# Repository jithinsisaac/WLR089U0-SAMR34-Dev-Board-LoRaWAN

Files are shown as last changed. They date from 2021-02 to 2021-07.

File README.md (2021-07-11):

### WLR089U0-SAMR34-Dev-Board-LoRaWAN
Development board for Microchip's WLR089U0 LoRaWAN module consisting of the SAMR34 SiP IC 

### PCB Information:
1.  SAMR34 based SiP
2.  Inbuilt u.Fl connector, so no need to worry about RF tuning and impedance matching for PCB tracks
3.  Sleep current of ~2.4uA in Standby mode!
4.  Powered from the USB port
5.  Microchip MCP1700 3.3V LDO
6.  Inbuilt CH340E USB-UART converter. No need for any extra adapter. Serial comm works directly via the USB. CH340E does not require external crystals.
7.  SWD programming via the Cortex debug pin

### Firmware for the board
1.  Use Microchip Studio for firmware programming
2.  Install/Update Microchip ASF 3.48
3.  Open a New Example Project, search for SAMR34
4.  Use 'LoRaWAN Mote Application - SAMR34 Xplained Pro' project
5.  Be sure to choose MLS 1_0_P_4 from ASF version 3.48 (requires LoRaWAN core 1.0.2)
6.  Newer version of MLS 1_0_P_5 requires LoRaWAN core 1.0.4, which may not be compatible with many networks.

### Snapshots:
1. PCB Front
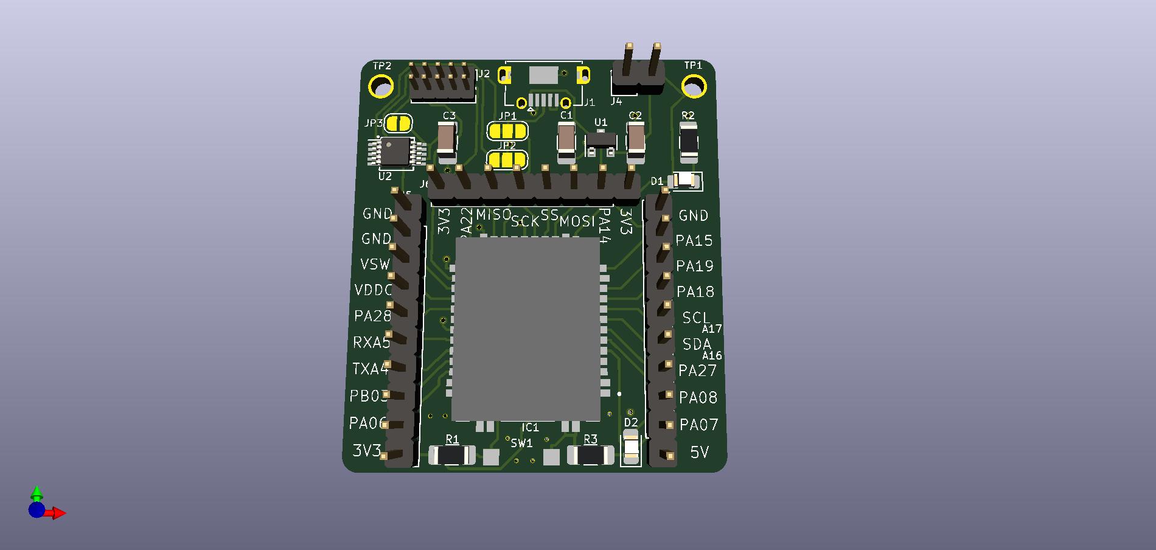
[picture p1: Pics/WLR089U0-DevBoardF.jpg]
Front PCB

2. PCB Back
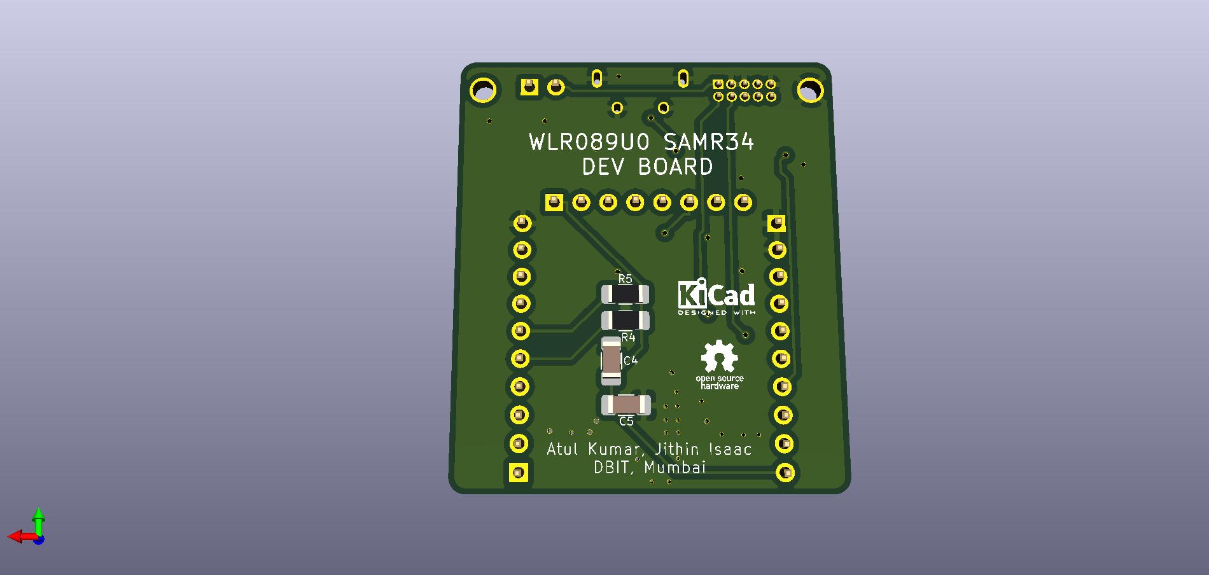
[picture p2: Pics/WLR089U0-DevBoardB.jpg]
Back PCB

3. Finished product 
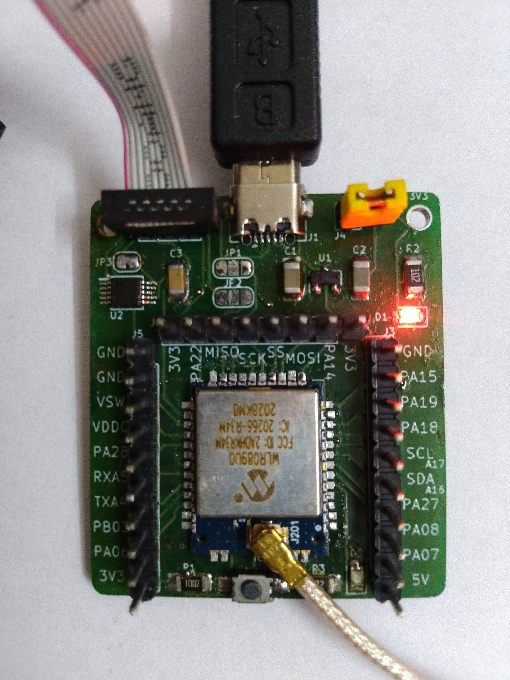
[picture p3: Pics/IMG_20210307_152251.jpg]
Product


### Credits
Atul Kumar  (Third Year student, AY2020-2021)  
Jithin Saji Isaac (Assistant Professor, Dept. of EXTC)  
Don Bosco Institute of Technology, Mumbai  
Feb 2021

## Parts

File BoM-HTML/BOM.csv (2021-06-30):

Designator | Quantity | Value | Manufacturer_Part_Number
C1 C2 | 2 | 1u | 1206B105K250CT
C3 C4 C5 | 3 | 100n | 1206B104K500CT
D1 | 1 | Red | RD-LED-0805
D2 | 1 | Green | RD-LED-0805
IC1 | 1 | WLR089U0-I_RM | WLR089U0-I/RM
J1 | 1 | USB_B_Micro | DNP
J2 | 1 | Conn_ARM_JTAG_SWD_10 | DNP
J3 J5 | 2 | Conn_01x10_Female | DNP
J4 | 1 | Conn_01x02_Male | DNP
J6 | 1 | Conn_01x08_Male | DNP
JP1 JP2 | 2 | SolderJumper_3_Bridged12 | DNP
JP3 | 1 | SolderJumper_2_Open | DNP
R1 | 1 | 10k | DNP
R2 R3 | 2 | 1k | DNP
R4 R5 | 2 | 4.7k | DNP
SW1 | 1 | SW_Push | DNP
TP1 TP2 | 2 | TestPoint | DNP
U1 | 1 | MCP1700-3302E_SOT23 | DNP
U2 | 1 | CH304E | DNP

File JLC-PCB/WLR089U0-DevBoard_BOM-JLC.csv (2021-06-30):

Comment | Designator | Footprint | LCSC
1u | C1,C2 | Capacitor_SMD:C_1206_3216Metric_Pad1.33x1.80mm_HandSolder | C412632
100n | C3,C4,C5 | Capacitor_SMD:C_1206_3216Metric_Pad1.33x1.80mm_HandSolder | C692631
Red | D1 | LED_SMD:LED_0805_2012Metric_Pad1.15x1.40mm_HandSolder | C84260
Green | D2 | LED_SMD:LED_0805_2012Metric_Pad1.15x1.40mm_HandSolder | C84260
WLR089U0-I_RM | IC1 | SamacSys_Parts:WLR089U0IRM
USB_B_Micro | J1 | Connector_USB:USB_Micro-AB_Molex_47590-0001 | C77238
Conn_ARM_JTAG_SWD_10 | J2 | Connector_PinHeader_1.27mm:PinHeader_2x05_P1.27mm_Vertical | C124387
Conn_01x10_Female | J3,J5 | Connector_PinHeader_2.54mm:PinHeader_1x10_P2.54mm_Vertical | C57369
Conn_01x02_Male | J4 | Connector_PinHeader_2.54mm:PinHeader_1x02_P2.54mm_Vertical | C124375
Conn_01x08_Male | J6 | Connector_PinHeader_2.54mm:PinHeader_1x08_P2.54mm_Vertical | C124381
SolderJumper_3_Bridged12 | JP1,JP2 | Jumper:SolderJumper-3_P1.3mm_Bridged12_RoundedPad1.0x1.5mm_NumberLabels
SolderJumper_2_Open | JP3 | Jumper:SolderJumper-2_P1.3mm_Open_RoundedPad1.0x1.5mm
10k | R1 | Resistor_SMD:R_1206_3216Metric_Pad1.42x1.75mm_HandSolder | C17902
1k | R2,R3 | Resistor_SMD:R_1206_3216Metric_Pad1.42x1.75mm_HandSolder | C1469
4.7k | R4,R5 | Resistor_SMD:R_1206_3216Metric_Pad1.42x1.75mm_HandSolder | C104821
SW_Push | SW1 | WLR089u0-DevBoard:Tactile Switch 3x4x2mm | C455280
TestPoint | TP1,TP2 | MountingHole:MountingHole_2.2mm_M2_DIN965_Pad_TopBottom
MCP1700-3302E_SOT23 | U1 | Package_TO_SOT_SMD:SOT-23 | C39051
CH304E | U2 | Package_SO:MSOP-10_3x3mm_P0.5mm | C99652

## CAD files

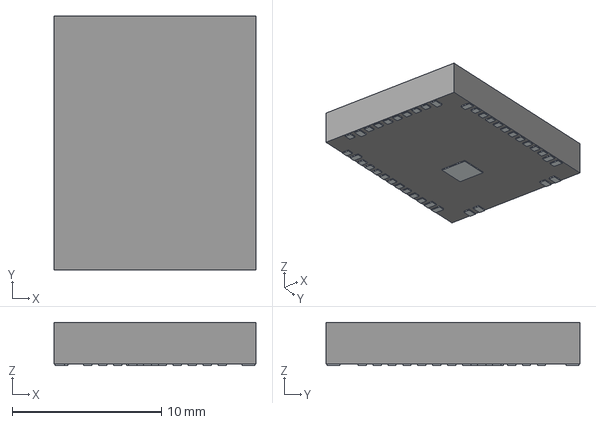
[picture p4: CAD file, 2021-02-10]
3DShapes/WLR089U0-I_RM.stp
13.5 x 17.0 x 2.90 mm
Pins

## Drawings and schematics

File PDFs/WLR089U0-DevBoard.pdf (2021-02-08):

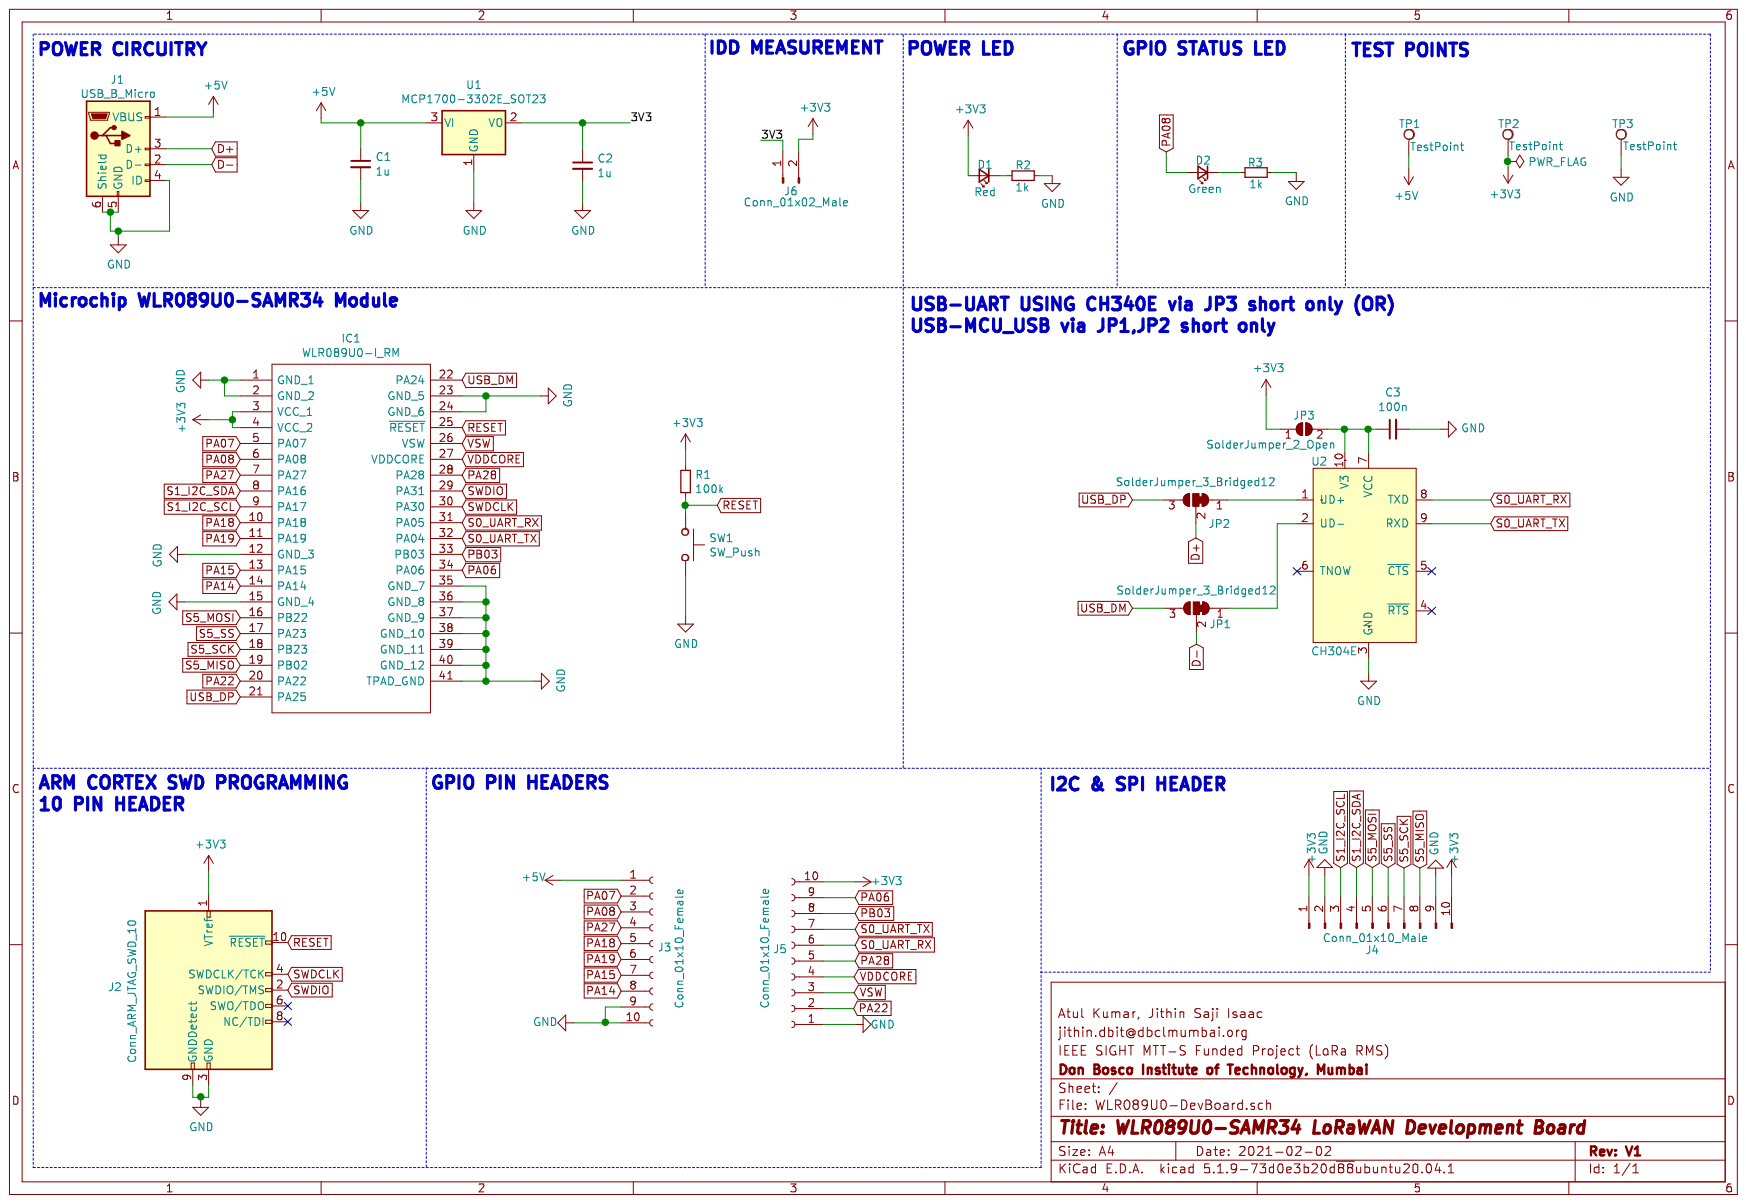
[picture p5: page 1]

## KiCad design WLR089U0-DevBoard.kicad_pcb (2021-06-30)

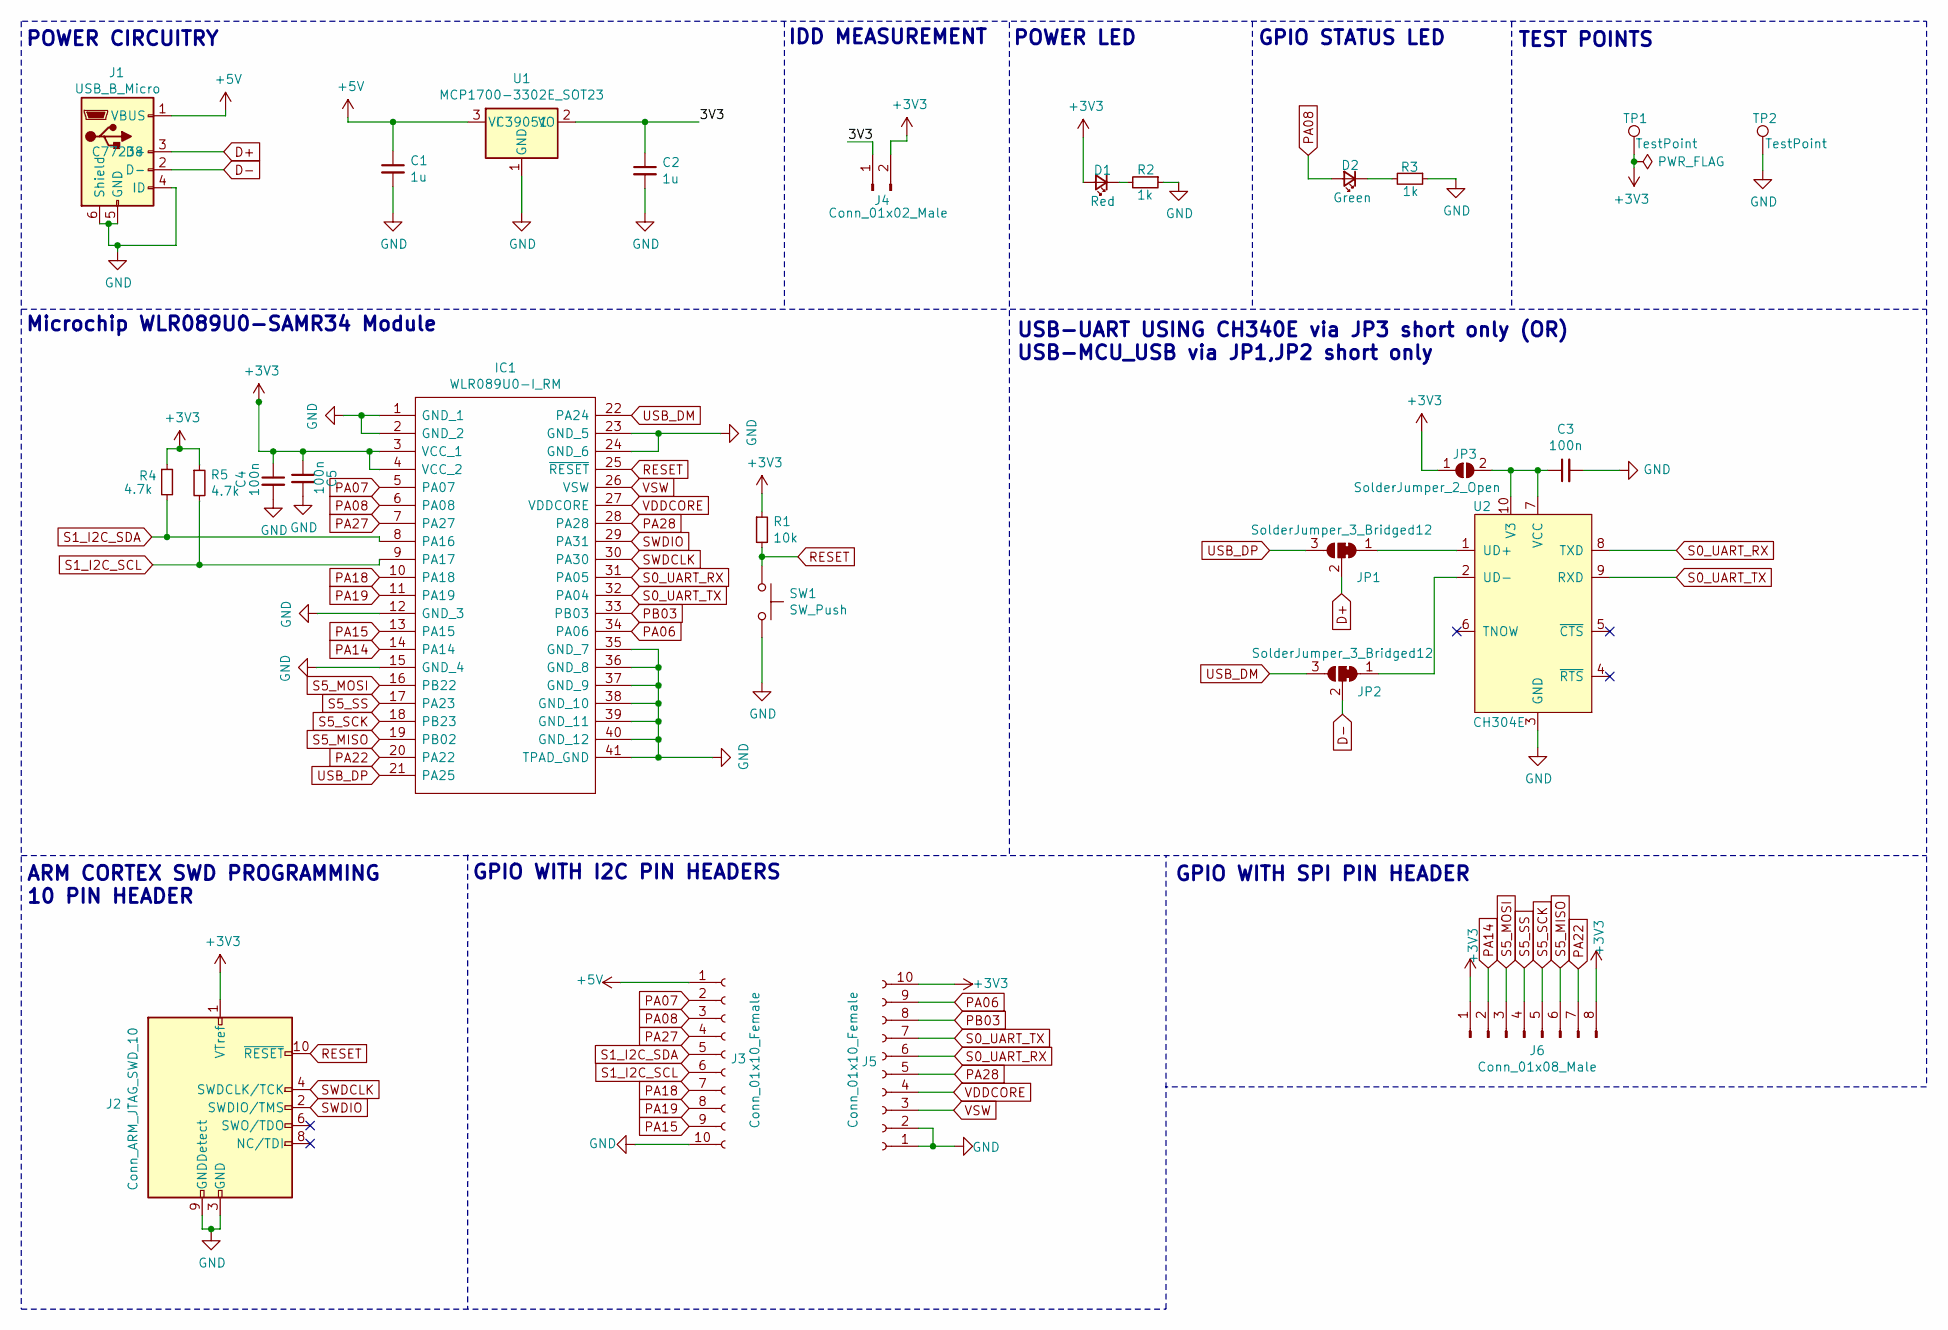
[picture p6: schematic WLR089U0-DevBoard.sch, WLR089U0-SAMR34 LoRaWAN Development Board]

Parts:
C1, C2: 1u; C_1206_3216Metric_Pad1.33x1.80mm_HandSolder; Manufacturer_Part_Number 1206B105K250CT; LCSC C412632
C3, C4, C5: 100n; C_1206_3216Metric_Pad1.33x1.80mm_HandSolder; Manufacturer_Part_Number 1206B104K500CT; LCSC C692631
D1: Red; LED_0805_2012Metric_Pad1.15x1.40mm_HandSolder; Manufacturer_Part_Number RD-LED-0805; LCSC C84260
D2: Green; LED_0805_2012Metric_Pad1.15x1.40mm_HandSolder; Manufacturer_Part_Number RD-LED-0805; LCSC C84260
IC1: WLR089U0-I_RM; WLR089U0IRM; Mouser Part Number 579-WLR089U0-I/RM
J1: USB_B_Micro; USB_Micro-AB_Molex_47590-0001; LCSC C77238
J2: Conn_ARM_JTAG_SWD_10; PinHeader_2x05_P1.27mm_Vertical; LCSC C124387
J3, J5: Conn_01x10_Female; PinHeader_1x10_P2.54mm_Vertical; LCSC C57369
J4: Conn_01x02_Male; PinHeader_1x02_P2.54mm_Vertical; LCSC C124375
J6: Conn_01x08_Male; PinHeader_1x08_P2.54mm_Vertical; LCSC C124381
JP1, JP2: SolderJumper_3_Bridged12; SolderJumper-3_P1.3mm_Bridged12_RoundedPad1.0x1.5mm_NumberL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
JP3: SolderJumper_2_Open; SolderJumper-2_P1.3mm_Open_RoundedPad1.0x1.5mm
R1: 10k; R_1206_3216Metric_Pad1.42x1.75mm_HandSolder; LCSC C17902
R2, R3: 1k; R_1206_3216Metric_Pad1.42x1.75mm_HandSolder; LCSC C1469
R4, R5: 4.7k; R_1206_3216Metric_Pad1.42x1.75mm_HandSolder; LCSC C104821
SW1: SW_Push; Tactile Switch 3x4x2mm; LCSC C455280
TP1, TP2: TestPoint; MountingHole_2.2mm_M2_DIN965_Pad_TopBottom
U1: MCP1700-3302E_SOT23; SOT-23; LCSC C39051
U2: CH304E; MSOP-10_3x3mm_P0.5mm; LCSC C99652

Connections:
+3V3: C4.1, C5.1, D1.2 (A), IC1.3 (VCC_1), IC1.4 (VCC_2), J2.1 (VTref), J4.2, J5.10, J6.1, J6.8, JP3.1 (A), R1.1, R4.1, R5.1, TP1.1
+5V: C1.1, J1.1 (VBUS), J3.1, U1.3 (VI)
/3V3: C2.1, J4.1, U1.2 (VO)
D+: J1.3 (D+), JP1.2 (C)
D-: J1.2 (D-), JP2.2 (C)
GND: C1.2, C2.2, C3.2, C4.2, C5.2, IC1.1 (GND_1), IC1.2 (GND_2), IC1.12 (GND_3), IC1.15 (GND_4), IC1.23 (GND_5), IC1.24 (GND_6), IC1.35 (GND_7), IC1.36 (GND_8), IC1.37 (GND_9), IC1.38 (GND_10), IC1.39 (GND_11), IC1.40 (GND_12), IC1.41 (TPAD_GND), J1.4 (ID), J1.5 (GND), J1.6 (Shield), J2.3 (GND), J2.5 (GND), J2.9 (GNDDetect), J3.10, J5.1, J5.2, R2.1, R3.1, SW1.2, TP2.1, U1.1 (GND), U2.3 (GND)
unnamed: C3.1, JP3.2 (B), U2.7 (VCC), U2.10 (V3)
unnamed: D1.1 (K), R2.2
unnamed: D2.1 (K), R3.2
unnamed: JP1.1 (A), U2.1 (UD+)
unnamed: JP2.1 (A), U2.2 (UD-)
PA06: IC1.34 (PA06), J5.9
PA07: IC1.5 (PA07), J3.2
PA08: D2.2 (A), IC1.6 (PA08), J3.3
PA14: IC1.14 (PA14), J6.2
PA15: IC1.13 (PA15), J3.9
PA18: IC1.10 (PA18), J3.7
PA19: IC1.11 (PA19), J3.8
PA22: IC1.20 (PA22), J6.7
PA27: IC1.7 (PA27), J3.4
PA28: IC1.28 (PA28), J5.5
PB03: IC1.33 (PB03), J5.8
RESET: IC1.25 (~RESET), J2.10 (~RESET~), R1.2, SW1.1
S0_UART_RX: IC1.31 (PA05), J5.6, U2.8 (TXD)
S0_UART_TX: IC1.32 (PA04), J5.7, U2.9 (RXD)
S1_I2C_SCL: IC1.9 (PA17), J3.6, R5.2
S1_I2C_SDA: IC1.8 (PA16), J3.5, R4.2
S5_MISO: IC1.19 (PB02), J6.6
S5_MOSI: IC1.16 (PB22), J6.3
S5_SCK: IC1.18 (PB23), J6.5
S5_SS: IC1.17 (PA23), J6.4
SWDCLK: IC1.30 (PA30), J2.4 (SWDCLK/TCK)
SWDIO: IC1.29 (PA31), J2.2 (SWDIO/TMS)
USB_DM: IC1.22 (PA24), JP2.3 (B)
USB_DP: IC1.21 (PA25), JP1.3 (B)
VDDCORE: IC1.27 (VDDCORE), J5.4
VSW: IC1.26 (VSW), J5.3

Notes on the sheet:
ARM CORTEX SWD PROGRAMMING 10 PIN HEADER
Microchip WLR089U0-SAMR34 Module
POWER CIRCUITRY
POWER LED
GPIO STATUS LED
USB-UART USING CH340E via JP3 short only (OR) USB-MCU_USB via JP1,JP2 short only
GPIO WITH I2C PIN HEADERS
GPIO WITH SPI PIN HEADER
IDD MEASUREMENT
TEST POINTS

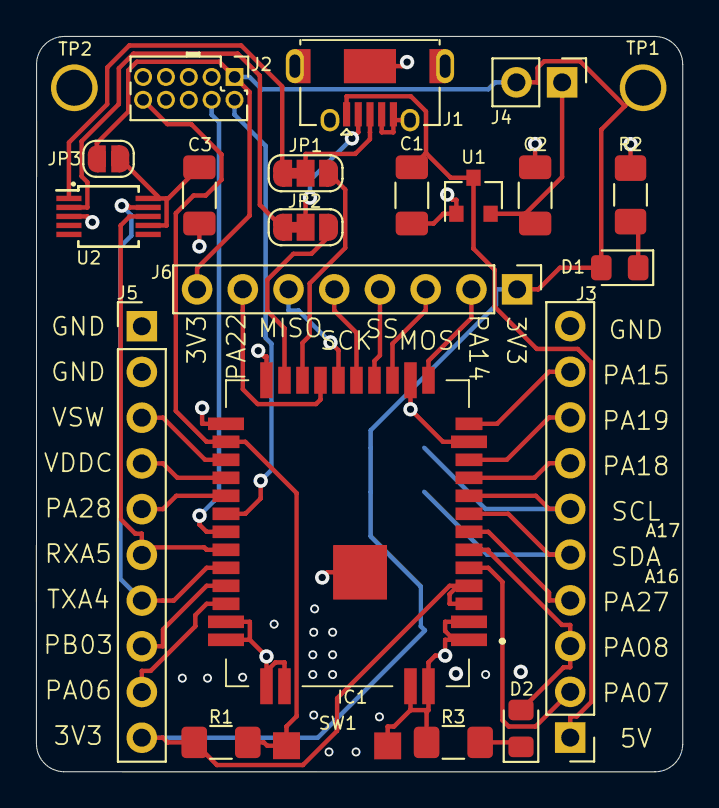
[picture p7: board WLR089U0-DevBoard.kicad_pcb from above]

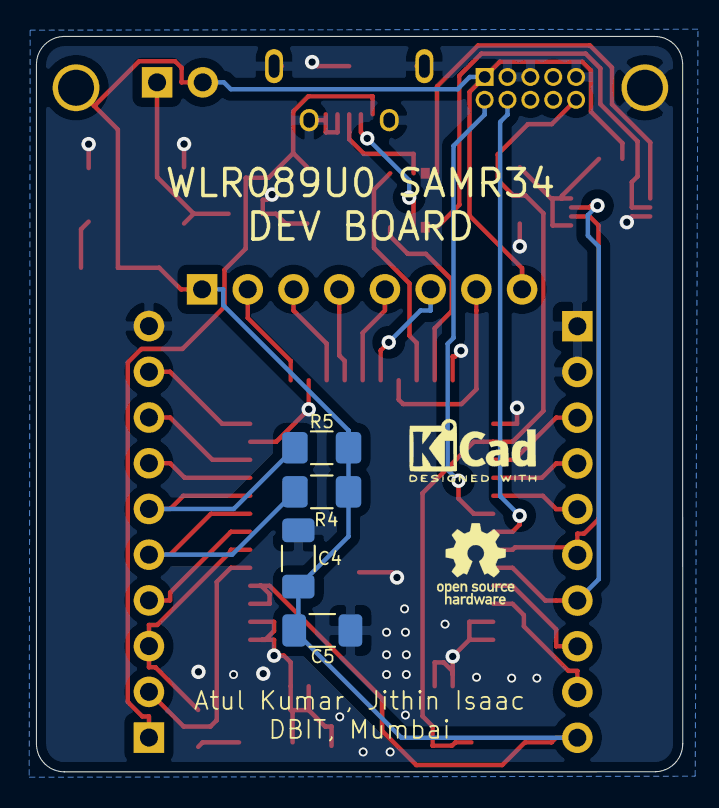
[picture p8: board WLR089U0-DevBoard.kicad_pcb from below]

Board: 2 copper layers, 35.9 x 40.9 mm, 28 parts (5 on the bottom side), 37 nets.

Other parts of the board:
KiCad: LOGO; KiCad-Logo2_8X4mm_SilkScreen

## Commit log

2021-02-03 Atul Kumars initial KiCad schematic
    [LoRa wan.kicad_pcb, LoRa wan.sch]
2021-02-04 Renamed Files
    [WLR089U0-DevBoard.kicad_pcb, WLR089U0-DevBoard.sch]
2021-02-04 edited schematic
    [WLR089U0-DevBoard.sch]
2021-02-04 Edited power symbols, ch340e needs to be made
    [WLR089U0-DevBoard.kicad_pcb, WLR089U0-DevBoard.sch]
2021-02-04 Power supply done and ch304e remaining
    [WLR089U0-DevBoard.sch]
2021-02-04 pins changed and ch304e symbol done
    [WLR089U0-DevBoard.sch]
2021-02-04 pins done and symbol ch304e
    [WLR089U0-DevBoard.sch]
2021-02-04 blue box and final version done
    [WLR089U0-DevBoard.sch]
2021-02-04 Beautified schematic layout, ERC pending
    [WLR089U0-DevBoard.sch]
2021-02-04 final schematic
    [WLR089U0-DevBoard.sch]
2021-02-05 Schematic done
    [WLR089U0-DevBoard.sch]
2021-02-05 Schematic done. reworked drc on test pts
    [WLR089U0-DevBoard.sch]
2021-02-05 edited date
    [WLR089U0-DevBoard.sch]
2021-02-05 done final editing
    [WLR089U0-DevBoard.sch]
2021-02-05 Edited pin placements in schematic
    [WLR089U0-DevBoard.sch]
2021-02-08 Added datasheets folder
    [WLR089U0-DevBoard.sch]
2021-02-08 PCB Schematic complete
2021-02-08 footprint assignment done
    [WLR089U0-DevBoard.sch]
2021-02-08 final footprint assignment
    [WLR089U0-DevBoard.sch]
2021-02-09 Updated footprint assignment
    [WLR089U0-DevBoard.sch]
2021-02-09 Updated footprint assignment & attached datasheet of switch
2021-02-10 pcb making started
    [WLR089U0-DevBoard.kicad_pcb]
2021-02-10 pcb editing
    [WLR089U0-DevBoard.kicad_pcb]
2021-02-10 removed 5v test point, edited layout edge,microusb edge
    [WLR089U0-DevBoard.kicad_pcb, WLR089U0-DevBoard.sch, WLR089U0-I_RM.stp]
2021-02-10 placement of ic2 done
    [WLR089U0-DevBoard.kicad_pcb, WLR089U0-DevBoard.sch]
2021-02-10 updated pin header to 8 pin, updated layout
    [WLR089U0-DevBoard.kicad_pcb, WLR089U0-DevBoard.sch]
2021-02-10 final pcb layout routing pending
    [WLR089U0-DevBoard.kicad_pcb]
2021-02-11 rearranged layout a bit
    [WLR089U0-DevBoard.kicad_pcb]
2021-02-11 pcb layer remaing
    [WLR089U0-DevBoard.kicad_pcb]
2021-02-11 green layer for gnd
    [WLR089U0-DevBoard.kicad_pcb]
2021-02-11 routing remaining
    [WLR089U0-DevBoard.kicad_pcb]
2021-02-11 routing done
    [WLR089U0-DevBoard.dsn, WLR089U0-DevBoard.kicad_pcb]
2021-02-11 reduced footprint ref size in silk screen
    [WLR089U0-DevBoard.kicad_pcb]
2021-02-12 labeling done
    [WLR089U0-DevBoard.kicad_pcb]
2021-02-13 coupling cap placement pending
    [WLR089U0-DevBoard.kicad_pcb, WLR089U0-DevBoard.sch]
2021-02-14 Changed orientation, rearranged symbols
    [WLR089U0-DevBoard.kicad_pcb, WLR089U0-DevBoard.sch]
2021-02-15 Increased board & SS size, completed layout,routing done. final inspection remains
    [WLR089U0-DevBoard.dsn, WLR089U0-DevBoard.kicad_pcb]
2021-02-17 Gerber generated
    [WLR089U0-DevBoard-B_Cu.gbr, WLR089U0-DevBoard-B_Mask.gbr, WLR089U0-DevBoard-B_Paste.gbr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]
2021-02-17 Edited test pads to remove MAR error, updated Gerber. Will send to fab if asked
    [WLR089U0-DevBoard-B_Cu.gbr, WLR089U0-DevBoard-B_Mask.gbr, WLR089U0-DevBoard-B_Paste.gbr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]
2021-03-02 Added HTML BoM
2021-03-02 Updated bom, chnged 100k to 10k for reset circuit
    [WLR089U0-DevBoard.kicad_pcb, WLR089U0-DevBoard.sch]
2021-03-03 new gerber
2021-06-30 Deleted extra gerber
    [BOM.csv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]
